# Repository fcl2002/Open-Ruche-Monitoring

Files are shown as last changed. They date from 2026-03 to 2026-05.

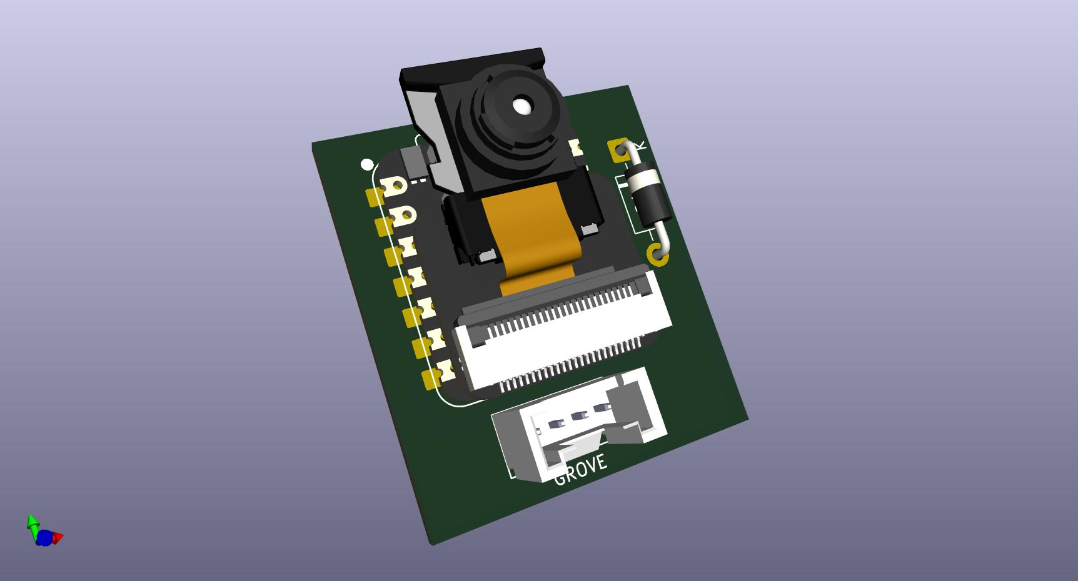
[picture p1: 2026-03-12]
hardware/3D_XIAO_view.jpg

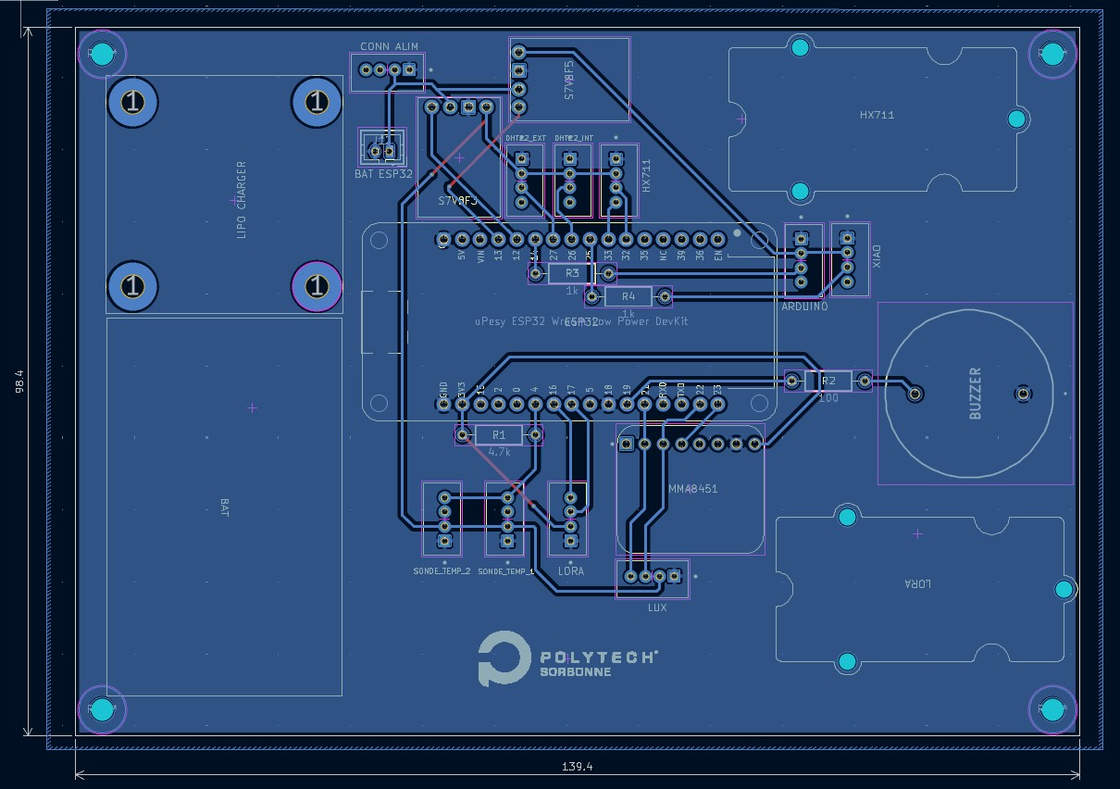
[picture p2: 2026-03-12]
hardware/pcb.jpg

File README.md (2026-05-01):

# Open Ruche 🐝 — BEE SMART

**Système de Monitorage Autonome de Ruches en Temps-réel**  
_Protéger les abeilles, préserver demain._

An intelligent beehive monitoring solution combining embedded AI, LoRaWAN communication, and solar power to help beekeepers protect their colonies and optimize hive management.

---

## Context & Motivation

Bee colonies face an accelerating global decline driven by the *Varroa destructor* mite, the Asian hornet (*Vespa velutina*), pesticides, and climate change. Continuous 24/7 manual monitoring is impossible for beekeepers — Open Ruche fills that gap with autonomous, real-time surveillance and automatic threat detection.

---

## Team

| Role | Name |
|---|---|
| **Project Manager, System Integration & Firmware Lead** | [Fernando COSTA LASMAR](https://www.linkedin.com/in/fernando-costa-lasmar/) |
| **AI/ML Engineer & Model Development** | [Flávio ROSIM DE SOUSA](https://www.linkedin.com/in/flávio-rosim-de-sousa/) |
| **Hardware Design & PCB Engineer** | [Matheus SISTON GALDINO](https://www.linkedin.com/in/matheussistongaldino/) |
| **Power Management & Solar Systems** | [Karim SAWAYA](https://www.linkedin.com/in/karim-sawaya-67ab87292/) |
| **HMI & Documentation** | [Yan DING](mailto:dingyan02040608@gmail.com) |

**Academic context:** Polytech Sorbonne — EI4 FISE | Projet Systèmes Embarqués IoT 2025-2026 | Groupe 4 – Ruche 9

---

## Solution Overview

Open Ruche is built around four integrated layers:

**Power Layer**
- Solar panel + battery with charge management module
- Switchable voltage regulator for load optimization
- Deep Sleep mode bringing average draw down to ~0.822 mA

**Sensor Layer (custom PCB)**
- Temperature: 2× DS18B20 probes (internal) + 1× DHT22 (external T°/humidity)
- Weight: HX711 load cell amplifier
- Light: LUX sensor
- Motion/safety: MMA8452 accelerometer, GPS module, buzzer alarm
- Air quality: gas/particle sensor (SEN0190)

**AI Processing Layer**
- Dual-core setup: Arduino Nano 3.3 (audio) + XIAO ESP32S3 (vision)
- TensorFlow Lite models running fully on-device
- **Audio classification model** — 86.45% accuracy on test data
  - Class 1: Normal activity
  - Class 2: Swarming
  - Class 3: Queenless colony
- **Hornet detection model (computer vision)** — 79.7% accuracy, F1-score 90%
  - Code 0: No hornet detected
  - Code 1: Hornet detected

**Communication & Cloud Layer**
- LoRaWAN module → The Things Network (TTN)
- Configurable uplink frequency via TTN downlink
- Cloud dashboards: BEEP Monitor + Datacake
- Real-time alerts and remote parameter configuration

---

## Software Architecture

The firmware implements a 4-state machine to minimise power consumption:

```
BOOT → INIT → LECTURE (sensors + AI) → DEEP SLEEP
              ↑___________________________________|
              Wake after configurable interval
```

- **INIT → LECTURE** triggered when LUX > 100 AND internal temp > 20 °C  
- **LECTURE → DEEP SLEEP** when LUX < 100 OR internal temp < 15 °C  
- LoRa downlink allows remote configuration of the sleep interval  
- Logging system for debugging and field maintenance

---

## Power Consumption

| Phase | Average Current |
|---|---|
| Active period (AI + sensors + LoRa) | ~85.8 mA |
| Deep Sleep | ~0.822 mA |

Charge breakdown per cycle (54 s total):
- AI (10 s): 0.414 mAh — 38%
- Sensors (15 s): 0.283 mAh — 26%
- LoRa (9 s): 0.117 mAh — 11%
- Deep Sleep (20 min): 0.274 mAh — 25%

**Estimated autonomy (1000 mAh battery):** ~13 days without solar charging.

---

## Project Status

| Objective | Status |
|---|---|
| Sensor accuracy & LoRa transmission | ✅ Done |
| Real-time image & audio AI detection | ✅ Done |
| Alarm creation & notifications | ✅ Done |
| Remote parameter & alarm configuration | ✅ Done |
| System energy autonomy | ✅ Done |
| PCB schematic & assembly | ✅ Done |
| Enclosure fabrication & prototype wiring | ✅ Done |
| Data display on cloud platforms | ✅ Done |
| Accelerometer for fall/theft detection | ❌ Not implemented |

---

## Getting Started

### Prerequisites

- Arduino IDE or PlatformIO
- KiCad (for hardware design)
- The Things Network account + LoRaWAN gateway access

### Quick Start

```bash
# Clone the repository
git clone https://github.com/[your-username]/OpenRuche.git
cd OpenRuche

# Project structure
# hardware/   — KiCad schematics & PCB files
# software/   — Firmware (Arduino / PlatformIO)
# ai/         — TensorFlow Lite model training scripts
# docs/       — Documentation & guides
```

For detailed development guidelines, see [CONTRIBUTING.md](CONTRIBUTING.md).

---

## License

This project is open-source. See [LICENSE](LICENSE) for details.

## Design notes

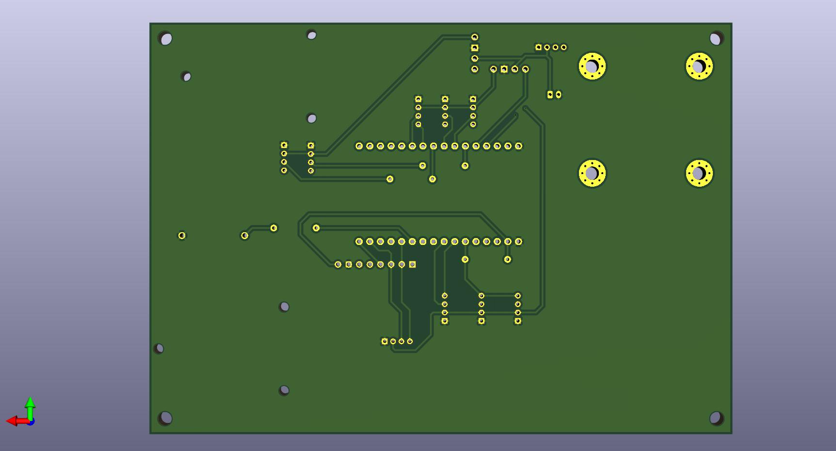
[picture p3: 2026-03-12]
hardware/PCB_bottom.jpg

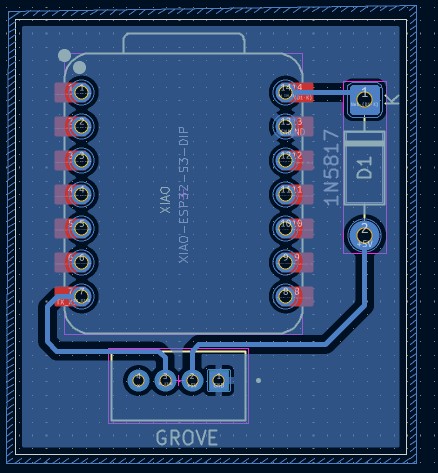
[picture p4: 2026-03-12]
hardware/pcb_xiao.jpg

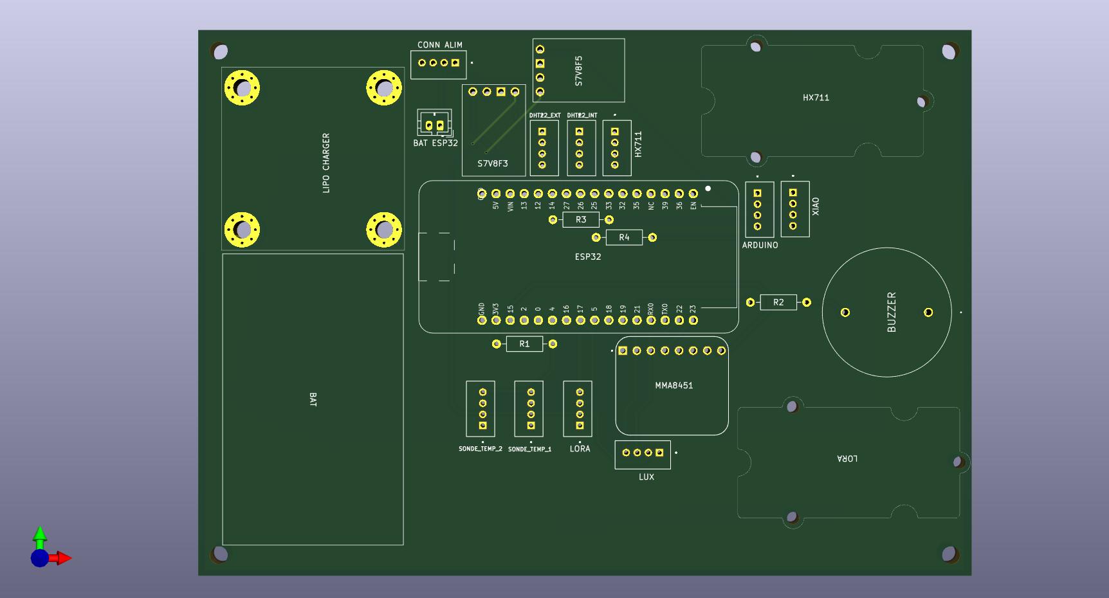
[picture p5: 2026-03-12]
hardware/PCB_top.jpg

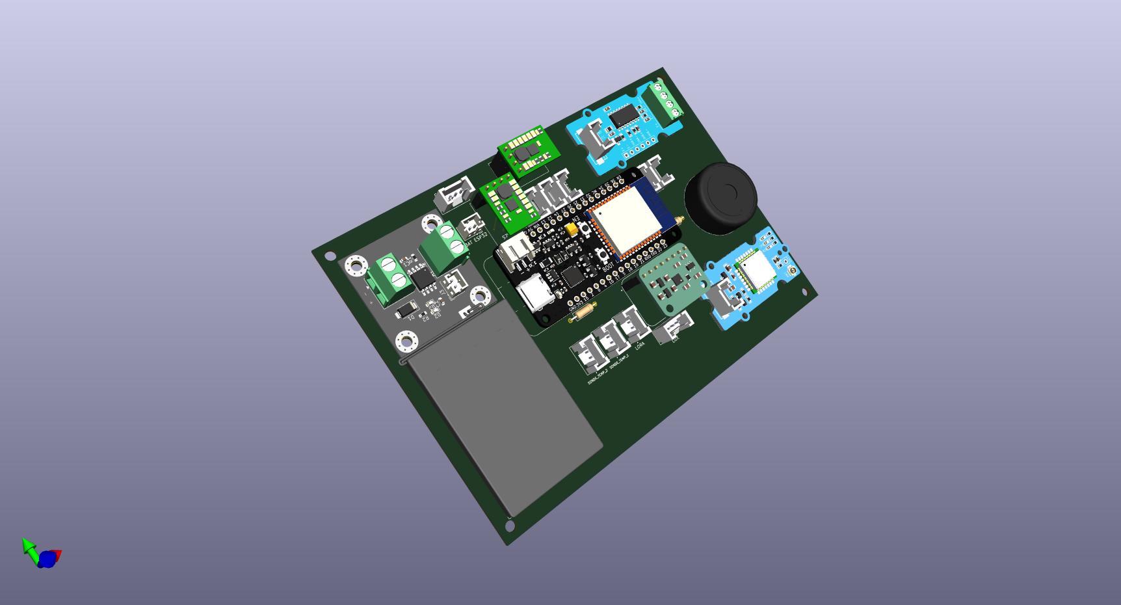
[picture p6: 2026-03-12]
hardware/3D_view.jpg

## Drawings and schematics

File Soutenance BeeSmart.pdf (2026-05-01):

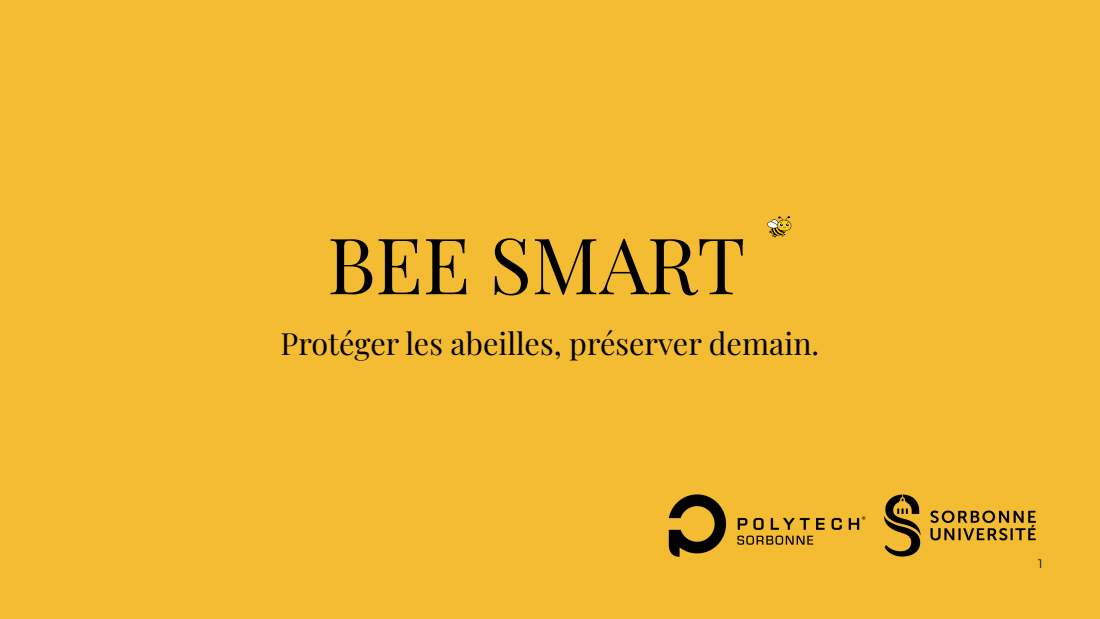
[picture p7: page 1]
BEE SMART

Protéger les abeilles, préserver demain.

E

QU

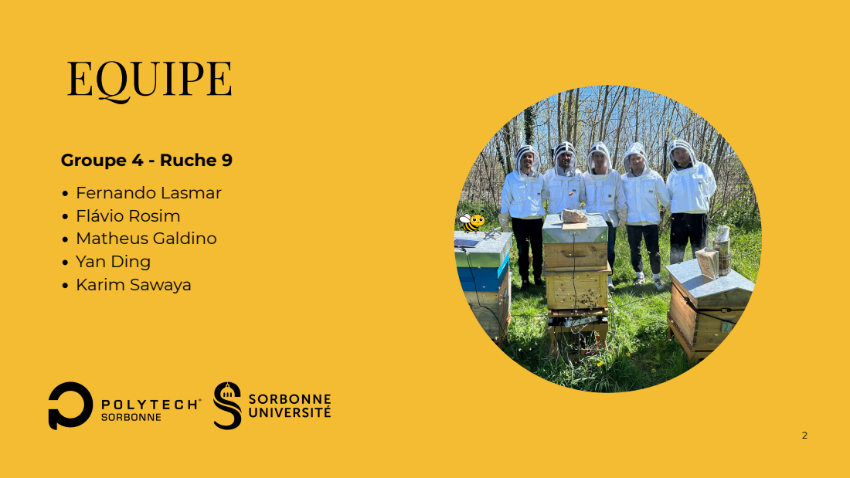
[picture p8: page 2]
Flá; vio; sim; aldin; Din; rim

# CONTEXTE

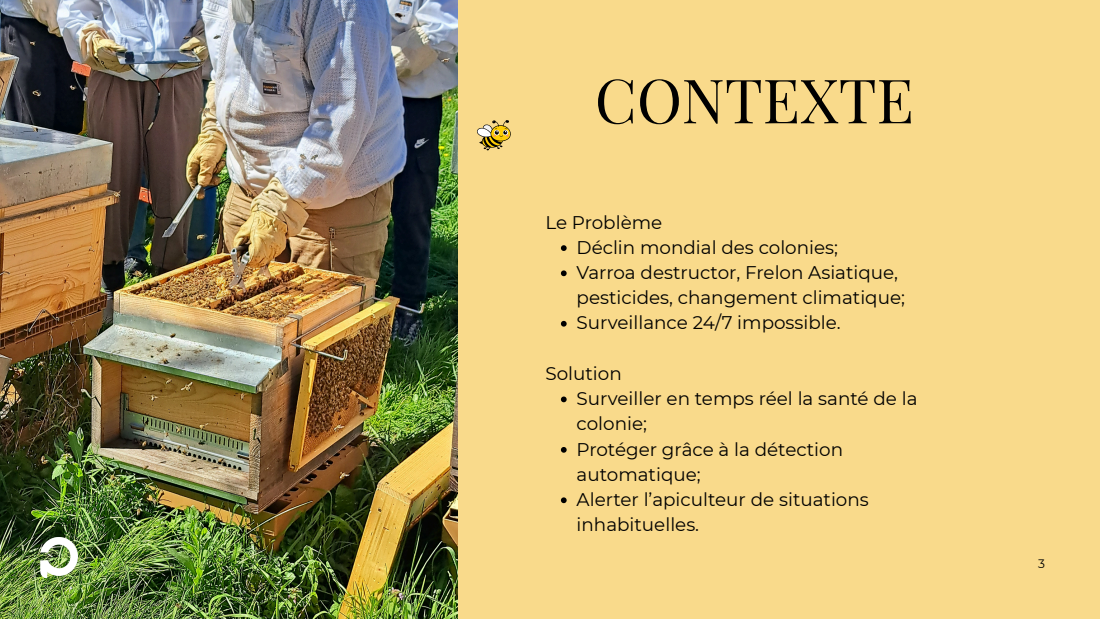
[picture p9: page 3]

Le Problème
Déclin mondial des colonies;
Varroa destructor, Frelon Asiatique,
pesticides, changement climatique;
Surveillance 24/7 impossible.

Solution
Surveiller en temps réel la santé de la
colonie;
Protéger grâce à la détection
automatique;
Alerter l’apiculteur de situations
inhabituelles.

# SOLUTION

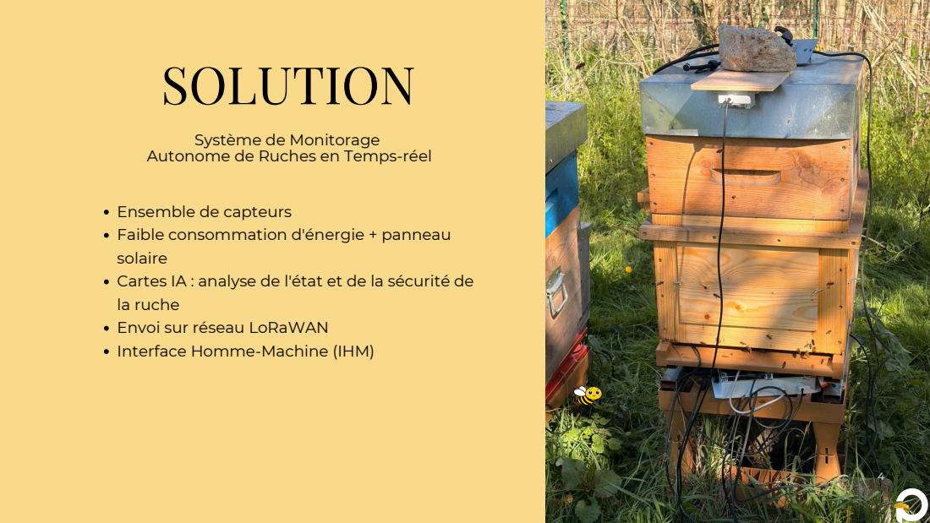
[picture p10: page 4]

Système de Monitorage
Autonome de Ruches en Temps-réel

Ensemble de capteurs
Faible consommation d'énergie + panneau
solaire
Cartes IA : analyse de l'état et de la sécurité de
la ruche
Envoi sur réseau LoRaWAN
Interface Homme-Machine (IHM)

# HARDWARE

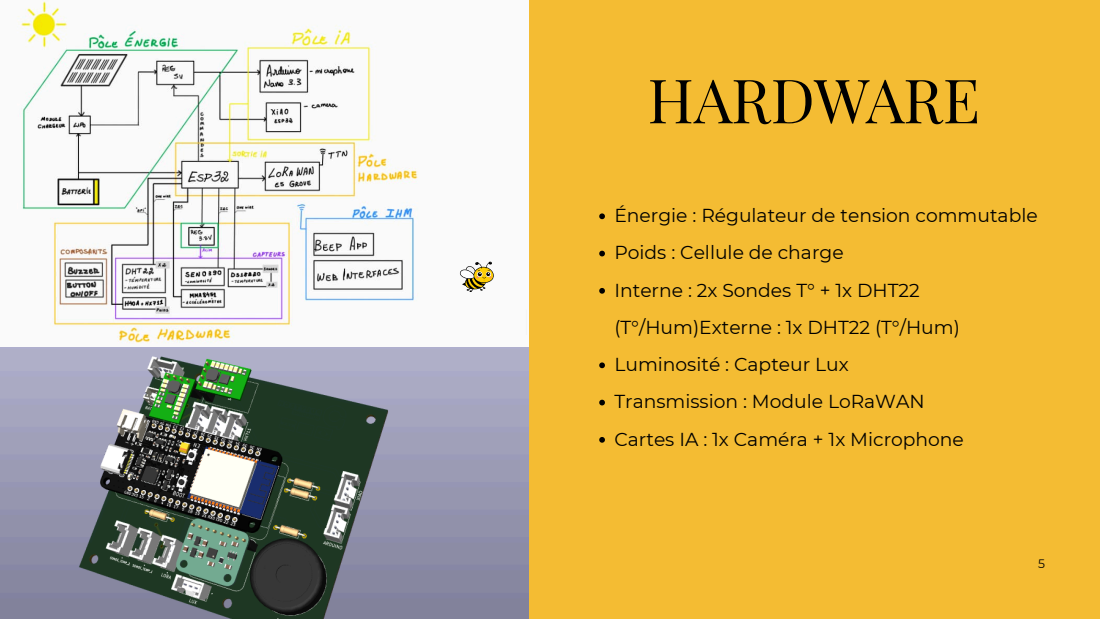
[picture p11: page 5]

Énergie : Régulateur de tension commutable
Poids : Cellule de charge
Interne : 2x Sondes T° + 1x DHT22
(T°/Hum)Externe : 1x DHT22 (T°/Hum)
Luminosité : Capteur Lux
Transmission : Module LoRaWAN
Cartes IA : 1x Caméra + 1x Microphone

S

O

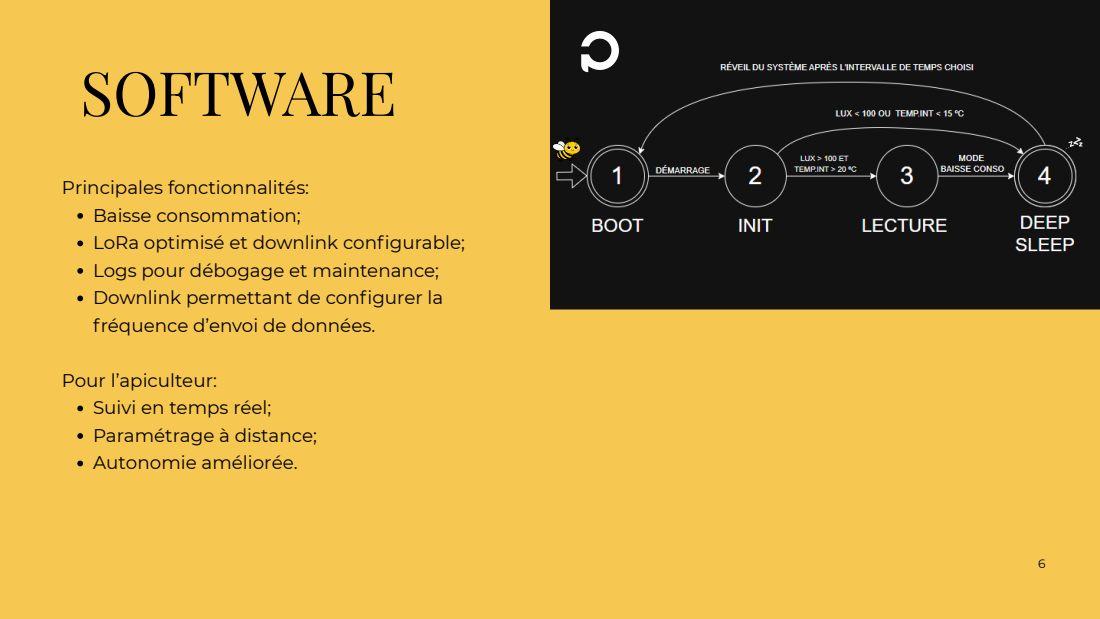
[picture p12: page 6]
rin; cip; ale; tio; alit; fig; ble; Logs pour débogage et maintenance; Downlink permettant de configurer la fréquence d’envoi de données. Pour l’apiculteur: Suivi en temps réel; Paramétrage à distance; Autonomie améliorée.

s: Baisse consommation; LoRa optimisé et downlin

# RÉSULTATS

IA

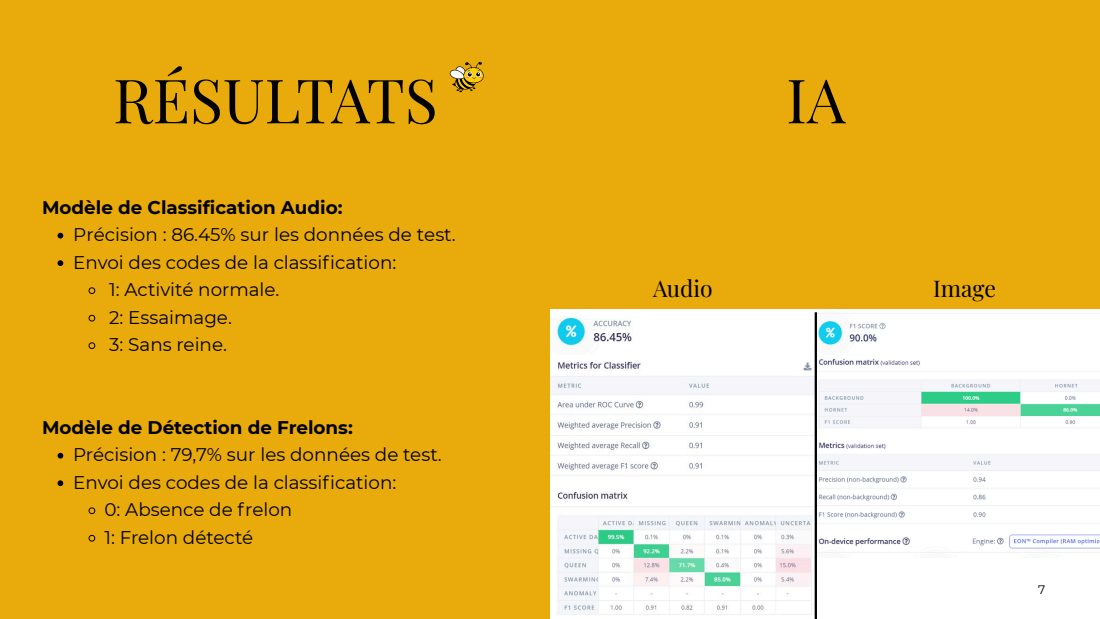
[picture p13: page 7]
Audio; Image

Modèle de Classification Audio:
Précision : 86.45% sur les données de test.
Envoi des codes de la classification:
1: Activité normale.
2: Essaimage.
3: Sans reine.

Modèle de Détection de Frelons:
Précision : 79,7% sur les données de test.
0: Absence de frelon
1: Frelon détecté

# CONSOMMATION

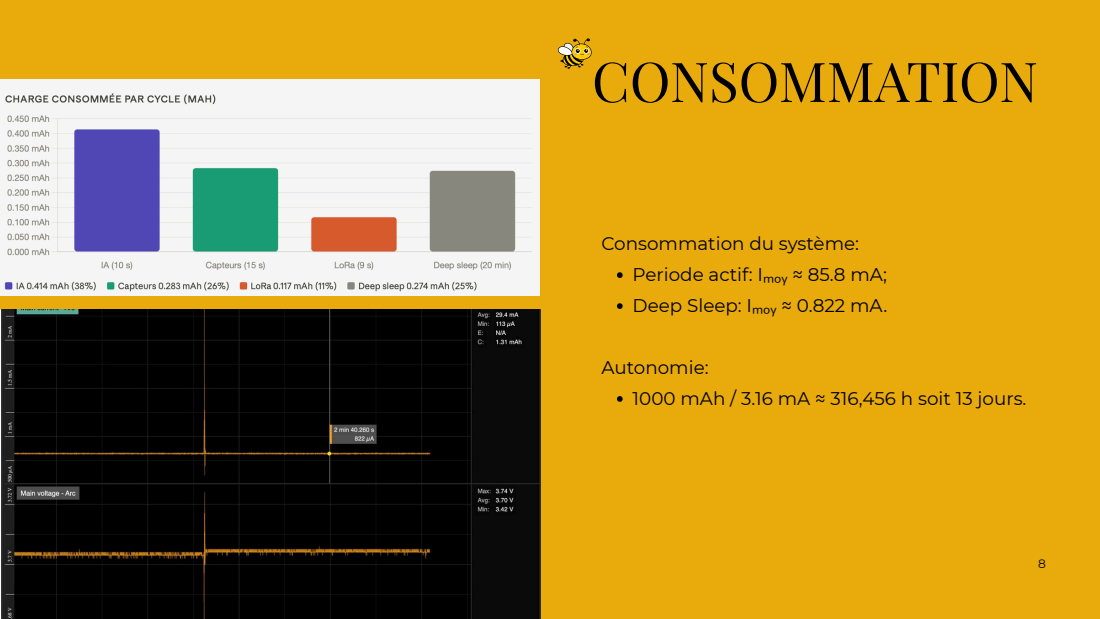
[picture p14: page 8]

Consommation du système:
Periode actif: Iₘₒᵧ ≈ 85.8 mA;
Deep Sleep: Iₘₒᵧ ≈ 0.822 mA.

Autonomie:
1000 mAh / 3.16 mA ≈ 316,456 h soit 13 jours.

# Suivi

# Objectifs

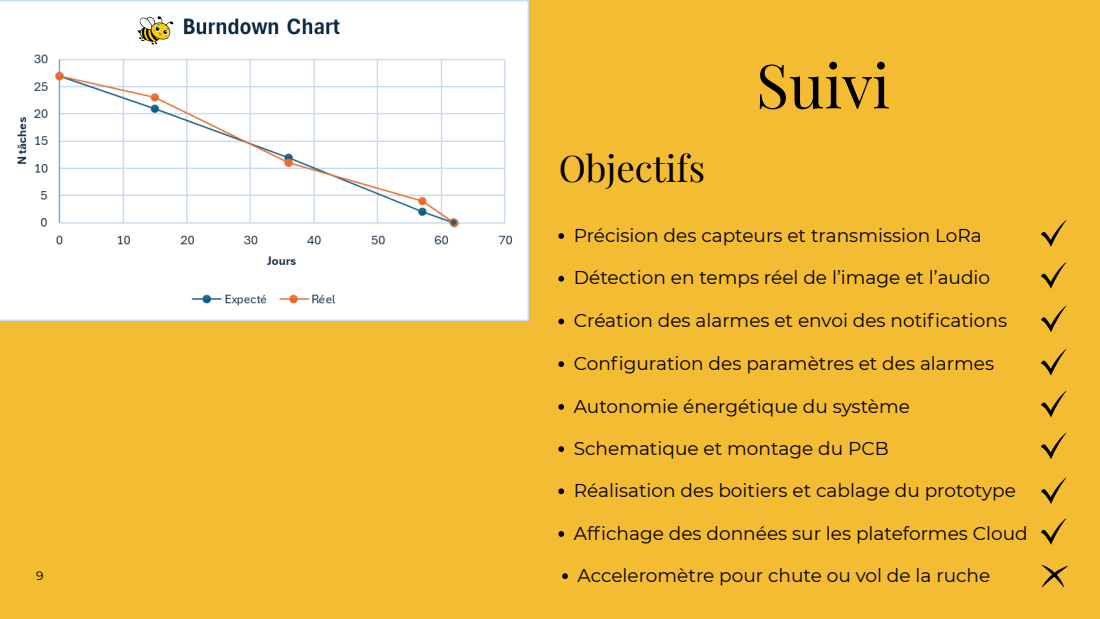
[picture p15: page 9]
Acceleromètre pour chute ou vol de la ruche

Précision des capteurs et transmission LoRa
Détection en temps réel de l’image et l’audio
Création des alarmes et envoi des notifications
Configuration des paramètres et des alarmes
Autonomie énergétique du système
Schematique et montage du PCB
Réalisation des boitiers et cablage du prototype
Affichage des données sur les plateformes Cloud

D

É

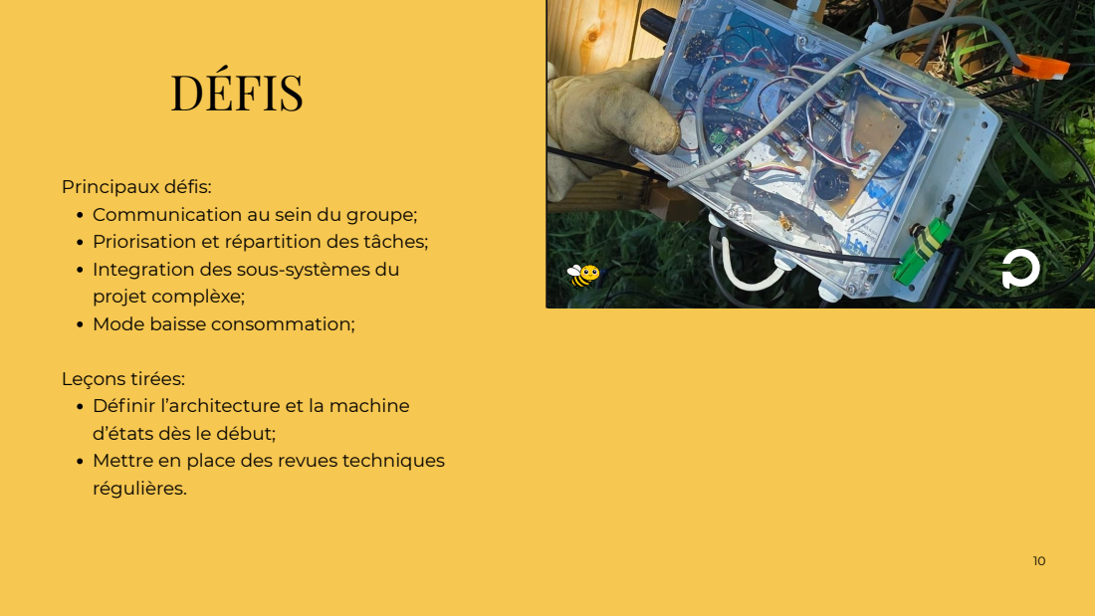
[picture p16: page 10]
rin; cip; fis: Communicatio; ein; uliè

e; Priorisation et répartition des tâches; Integration des sous-systèmes du projet complèxe; Mode baisse consommation; Leçons tirées: Définir l’architecture et la machine d’états dès le début; Mettre en place des revues technique

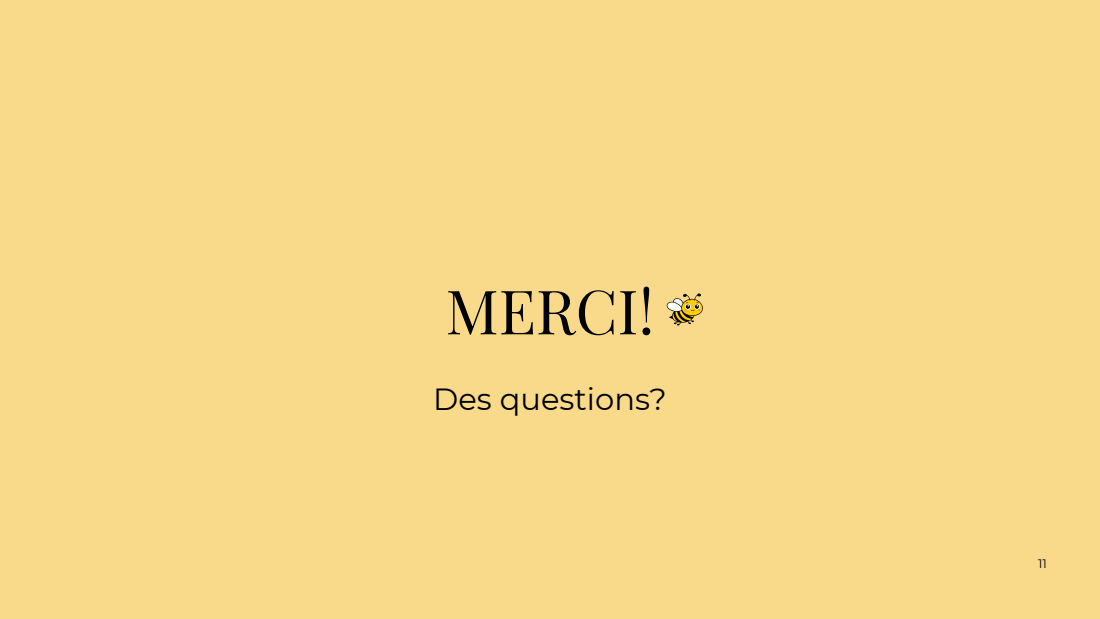
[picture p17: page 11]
MERCI!; Des questions?

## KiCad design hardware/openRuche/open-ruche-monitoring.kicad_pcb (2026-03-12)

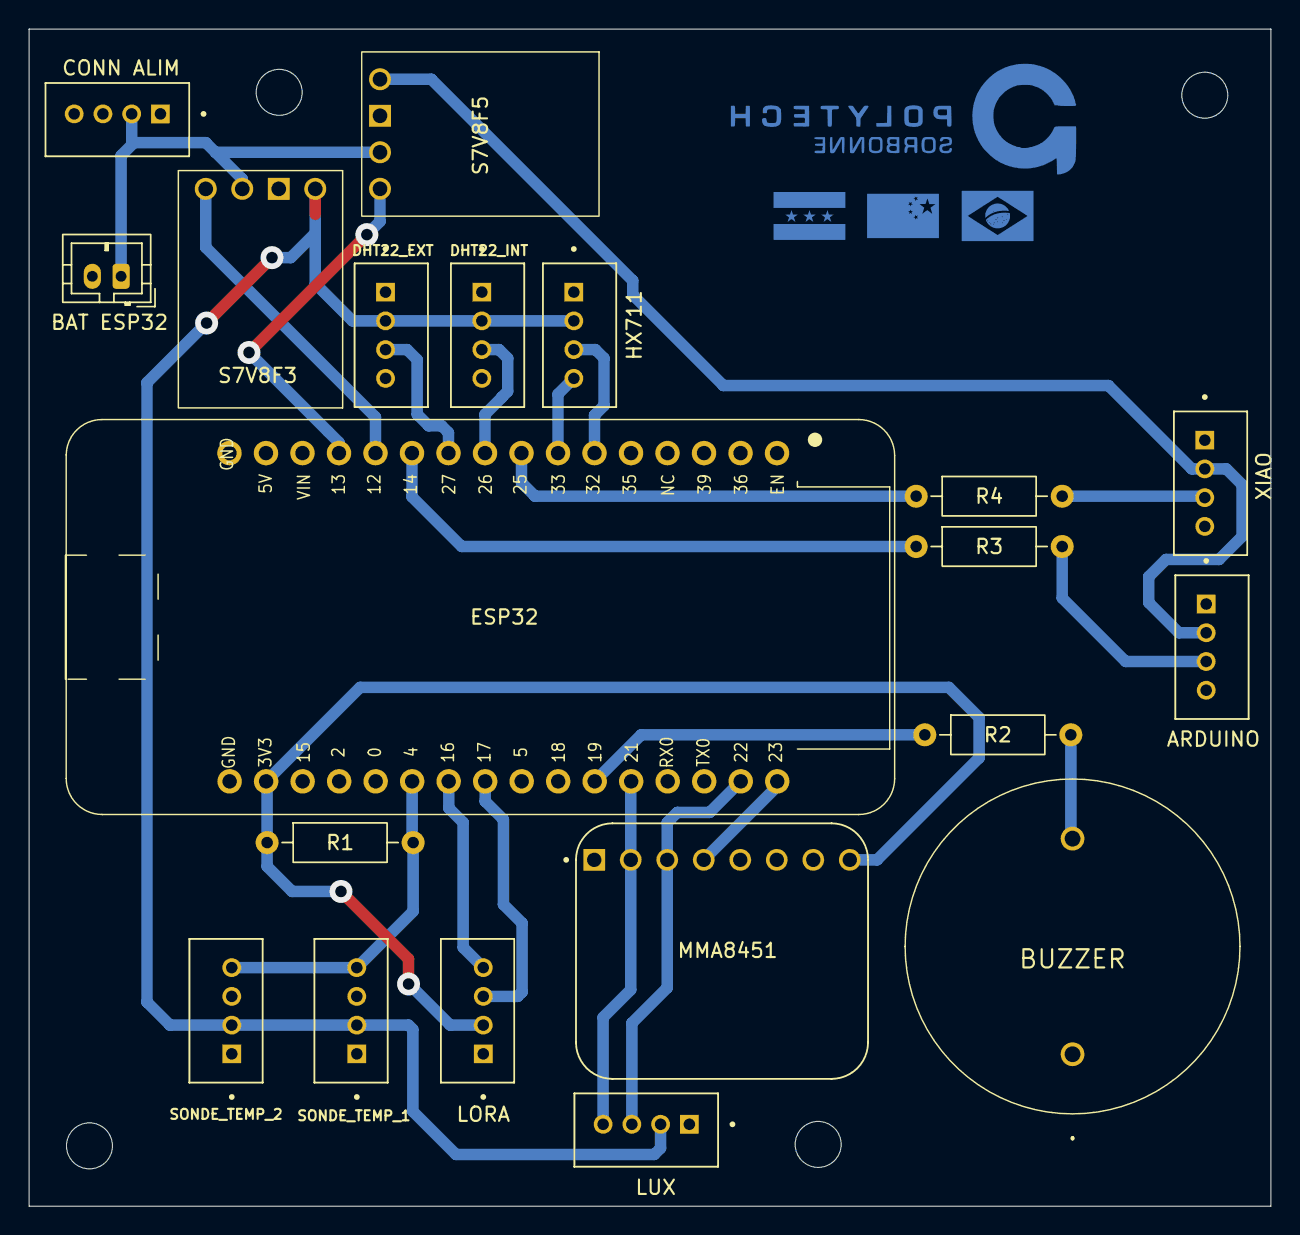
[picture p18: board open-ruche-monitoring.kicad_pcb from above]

Board: 2 copper layers, 86.4 x 81.9 mm, 20 parts (0 on the bottom side), 23 nets.

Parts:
BUZZER: KPEG222
J1: HX711; SEEED_110990030
J2: DHT22_EXT; SEEED_110990030
J3: DHT22_INT; SEEED_110990030
J4: SONDE_TEMP_1; SEEED_110990030
J5: SONDE_TEMP_2; SEEED_110990030
J6: LUX; SEEED_110990030
J7: LORA; SEEED_110990030
J8: ARDUINO; SEEED_110990030
J9: XIAO; SEEED_110990030
J10: MMA8451; MODULE_2019
J11: CONN ALIM; SEEED_110990030
J12: BAT ESP32; JST_PH_B2B-PH-K_1x02_P2.00mm_Vertical
R1: 4.7k; R_Axial_DIN0207_L6.3mm_D2.5mm_P10.16mm_Horizontal
R2: 100; R_Axial_DIN0207_L6.3mm_D2.5mm_P10.16mm_Horizontal
R3, R4: 1k; R_Axial_DIN0207_L6.3mm_D2.5mm_P10.16mm_Horizontal
U1: uPesy ESP32 Wroom Low Power DevKit; uPesy_ESP32_Wroom_Low_Power_DevKit
U2: S7V8F3; MODULE_STEP-DOWN_VOLTAGE_REGULATOR_D24V6F3
U3: S7V8F5; MODULE_STEP-DOWN_VOLTAGE_REGULATOR_D24V6F3

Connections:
/+3.3V: J7.2 (VCC), J10.8, R1.1, U1.31 (3V3)
/+3.3V_REG: J1.2 (VCC), J2.2 (VCC), J3.2 (VCC), J4.2 (VCC), J5.2 (VCC), J6.2 (VCC), U2.VOUT
/+3.7V: J11.2 (VCC), J12.1, U2.VIN, U3.VIN
/+5V_REG: J8.2 (VCC), J9.2 (VCC), U3.VOUT
/BUZZER: R2.1, U1.22 (GPIO19)
/DATA_DHT22_EXT: J2.3 (SIG1), U1.10 (GPIO27)
/DATA_DHT22_INT: J3.3 (SIG1), U1.9 (GPIO26)
/DOUT: J1.3 (SIG1), U1.6 (GPIO32)
/EN_3.3V_REG: U1.12 (GPIO12), U2.!SHDN (~SHDN)
/EN_5V_REG: U1.13 (GPIO13), U3.!SHDN (~SHDN)
/I1: J10.4, U1.17 (GPIO23)
/ONE_WIRE_TEMP: J4.4 (SIG2), J5.4 (SIG2), R1.2, U1.27 (GPIO4)
/PSCK: J1.4 (SIG2), U1.7 (GPIO33)
/RX_LORA: J7.3 (SIG1), U1.25 (GPIO17)
/SCL: J6.3 (SIG1), J10.3, U1.18 (GPIO22)
/SDA: J6.4 (SIG2), J10.2, U1.21 (GPIO21)
/TX_ARDUINO: R3.1, U1.11 (GPIO14)
/TX_LORA: J7.4 (SIG2), U1.26 (GPIO16)
/TX_XIAO: R4.1, U1.8 (GPIO25)
GND: BUZZER.1 (-), J1.1 (GND), J2.1 (GND), J3.1 (GND), J4.1 (GND), J5.1 (GND), J6.1 (GND), J7.1 (GND), J8.1 (GND), J9.1 (GND), J10.7, J11.1 (GND), J12.2, U1.16 (GND), U1.23 (GPIO18), U1.32 (GND), U2.GND, U3.GND
unnamed: J8.3 (SIG1), R3.2
unnamed: J9.3 (SIG1), R4.2
unnamed: BUZZER.2 (+), R2.2

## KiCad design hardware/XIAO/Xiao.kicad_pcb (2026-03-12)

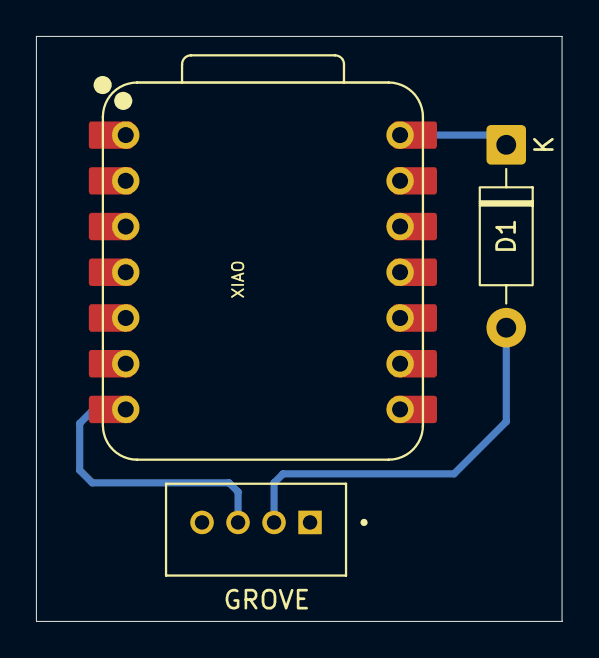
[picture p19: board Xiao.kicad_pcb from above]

Board: 2 copper layers, 29.2 x 32.5 mm, 3 parts (0 on the bottom side), 4 nets.

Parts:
D1: 1N5817; D_DO-41_SOD81_P10.16mm_Horizontal
J1: GROVE; SEEED_110990030
XIAO: XIAO-ESP32-S3-DIP

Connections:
/+5V: D1.2 (A), J1.2 (VCC)
/TX_XIAO: J1.3 (SIG1), XIAO.7 (GPIO43_D6_TX)
GND: J1.1 (GND), XIAO.13 (GND)
unnamed: D1.1 (K), XIAO.14 (VBUS)

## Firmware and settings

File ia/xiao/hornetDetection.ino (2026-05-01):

/* Edge Impulse Arduino examples - Modified for BeeGuard Production (Deep Sleep / Latch) */
#include <BeeGuardAI_Hornet_inferencing.h>
#include "edge-impulse-sdk/dsp/image/image.hpp"
#include "esp_camera.h"

#define UART_TX_PIN 43 // D6 on XIAO ESP32S3
#define UART_RX_PIN 44 // D7 on XIAO ESP32S3
HardwareSerial SerialVespa(1); // Uses ESP32 UART channel 1

// Select camera model for XIAO ESP32S3 Sense
#define CAMERA_MODEL_XIAO_ESP32S3 // Has PSRAM

#if defined(CAMERA_MODEL_XIAO_ESP32S3)
#define PWDN_GPIO_NUM     -1
#define RESET_GPIO_NUM    -1
#define XCLK_GPIO_NUM     10
#define SIOD_GPIO_NUM     40
#define SIOC_GPIO_NUM     39
#define Y9_GPIO_NUM       48
#define Y8_GPIO_NUM       11
#define Y7_GPIO_NUM       12
#define Y6_GPIO_NUM       14
#define Y5_GPIO_NUM       16
#define Y4_GPIO_NUM       18
#define Y3_GPIO_NUM       17
#define Y2_GPIO_NUM       15
#define VSYNC_GPIO_NUM    38
#define HREF_GPIO_NUM     47
#define PCLK_GPIO_NUM     13
#else
#error "Camera model not selected or not supported"
#endif

/* ------------------------------------------------------------------------- */
/* PRODUCTION SETTINGS AND ANTI-FALSE POSITIVE FILTER                        */
/* ------------------------------------------------------------------------- */
#define DEBUG_SERIAL           1     // Set to 1 only if you want to read human-readable error/timing prints
#define CONFIDENCE_THRESHOLD   0.70f 
#define REQUIRED_DETECTIONS    4     
#define TIME_WINDOW_MS         5000  // Time window: must detect 4 times within 5 seconds

const char* TARGET_LABEL = "Hornet"; 

// Native capture resolution
#define EI_CAMERA_RAW_FRAME_BUFFER_COLS           320
#define EI_CAMERA_RAW_FRAME_BUFFER_ROWS           240
#define EI_CAMERA_FRAME_BYTE_SIZE                 3

/* Private Variables ------------------------------------------------------- */
static bool debug_nn = false;
static bool is_initialised = false;
uint8_t *snapshot_buf; 

static unsigned long detection_times[REQUIRED_DETECTIONS] = {0};
static int detections_in_buffer = 0;

// ADDED: Alarm latch variable
static bool alarm_triggered = false; 

static camera_config_t camera_config = {
    .pin_pwdn = PWDN_GPIO_NUM,  .pin_reset = RESET_GPIO_NUM, .pin_xclk = XCLK_GPIO_NUM,
    .pin_sccb_sda = SIOD_GPIO_NUM, .pin_sccb_scl = SIOC_GPIO_NUM,
    .pin_d7 = Y9_GPIO_NUM, .pin_d6 = Y8_GPIO_NUM, .pin_d5 = Y7_GPIO_NUM, .pin_d4 = Y6_GPIO_NUM,
    .pin_d3 = Y5_GPIO_NUM, .pin_d2 = Y4_GPIO_NUM, .pin_d1 = Y3_GPIO_NUM, .pin_d0 = Y2_GPIO_NUM,
    .pin_vsync = VSYNC_GPIO_NUM, .pin_href = HREF_GPIO_NUM, .pin_pclk = PCLK_GPIO_NUM,
    .xclk_freq_hz = 20000000, .ledc_timer = LEDC_TIMER_0, .ledc_channel = LEDC_CHANNEL_0,
    .pixel_format = PIXFORMAT_JPEG, .frame_size = FRAMESIZE_QVGA,
    .jpeg_quality = 12, .fb_count = 1, .fb_location = CAMERA_FB_IN_PSRAM, .grab_mode = CAMERA_GRAB_WHEN_EMPTY,
};

bool ei_camera_init(void);
void ei_camera_deinit(void);
bool ei_camera_capture(uint32_t img_width, uint32_t img_height, uint8_t *out_buf);
static int ei_camera_get_data(size_t offset, size_t length, float *out_ptr);

void setup() {
    Serial.begin(115200);
    while (!Serial);
    
    SerialVespa.begin(115200, SERIAL_8N1, UART_RX_PIN, UART_TX_PIN);

    if (DEBUG_SERIAL) Serial.println("Starting BeeGuard - Production Mode (With Latch)");
    
    if (ei_camera_init() == false) {
        if (DEBUG_SERIAL) Serial.println("Camera initialization failed!");
        while(1); // Halt if camera fails to start
    }
}

void loop() {
    // ADDED: If hornet already detected, latch here! 
    // Keeps sending '1' and saves battery by not taking new photos, waiting for power cut.
    if (alarm_triggered) {
        SerialVespa.write(1);
        if (DEBUG_SERIAL) Serial.println("LATCHED STATE: Sending 1... Waiting for power cut.");
        ei_sleep(250); // Sends approximately 4 times per second
        return; 
    }

    ei_sleep(10); 
    unsigned long current_time = ei_read_timer_ms();

    snapshot_buf = (uint8_t*)malloc(EI_CAMERA_RAW_FRAME_BUFFER_COLS * EI_CAMERA_RAW_FRAME_BUFFER_ROWS * EI_CAMERA_FRAME_BYTE_SIZE);
    if(snapshot_buf == nullptr) return;

    ei::signal_t signal;
    signal.total_length = EI_CLASSIFIER_INPUT_WIDTH * EI_CLASSIFIER_INPUT_HEIGHT;
    signal.get_data = &ei_camera_get_data;

    if (ei_camera_capture((size_t)EI_CAMERA_RAW_FRAME_BUFFER_COLS, (size_t)EI_CAMERA_RAW_FRAME_BUFFER_ROWS, snapshot_buf) == false) {
        free(snapshot_buf);
        return;
    }

    uint8_t *inference_buf = (uint8_t*)malloc(EI_CLASSIFIER_INPUT_WIDTH * EI_CLASSIFIER_INPUT_HEIGHT * EI_CAMERA_FRAME_BYTE_SIZE);
    if(inference_buf == nullptr) {
        free(snapshot_buf); return;
    }

    ei::image::processing::crop_and_interpolate_rgb888(
        snapshot_buf, EI_CAMERA_RAW_FRAME_BUFFER_COLS, EI_CAMERA_RAW_FRAME_BUFFER_ROWS,
        inference_buf, EI_CLASSIFIER_INPUT_WIDTH, EI_CLASSIFIER_INPUT_HEIGHT);

    memcpy(snapshot_buf, inference_buf, EI_CLASSIFIER_INPUT_WIDTH * EI_CLASSIFIER_INPUT_HEIGHT * EI_CAMERA_FRAME_BYTE_SIZE);
    free(inference_buf);

    ei_impulse_result_t result = { 0 };
    EI_IMPULSE_ERROR err = run_classifier(&signal, &result, debug_nn);
    if (err != EI_IMPULSE_OK) {
        free(snapshot_buf); return;
    }

    if (DEBUG_SERIAL) {
        Serial.print("Inference OK | Timing: ");
        Serial.print(result.timing.classification);
        Serial.print("ms | ");
        
        bool saw_something = false;
        for (uint32_t i = 0; i < result.bounding_boxes_count; i++) {
            if (result.bounding_boxes[i].value > 0.40) { // Show if at least 40% confidence
                Serial.print("Detected: ");
                Serial.print(result.bounding_boxes[i].label);
                Serial.print(" (");
                Serial.print(result.bounding_boxes[i].value);
                Serial.print(")  ");
                saw_something = true;
            }
        }
        if (!saw_something) {
            Serial.print("Nothing on radar.");
        }
        Serial.println();
    }

    /* --------------------------------------------------------------------- */
    /* NEW LOGIC: SLIDING WINDOW WITH LATCHING                               */
    /* --------------------------------------------------------------------- */
    bool hornet_in_this_frame = false;

    for (uint32_t i = 0; i < result.bounding_boxes_count; i++) {
        ei_impulse_result_bounding_box_t bb = result.bounding_boxes[i];
        if (bb.value >= CONFIDENCE_THRESHOLD && strcmp(bb.label, TARGET_LABEL) == 0) {
            hornet_in_this_frame = true;
            break; 
        }
    }

    if (hornet_in_this_frame) {
        // Shift old history to the left
        for (int i = 0; i < REQUIRED_DETECTIONS - 1; i++) {
            detection_times[i] = detection_times[i+1];
        }
        // Store new detection in the most recent position (right)
        detection_times[REQUIRED_DETECTIONS - 1] = current_time;

        if (detections_in_buffer < REQUIRED_DETECTIONS) {
            detections_in_buffer++;
        }

        // If memory is full (we have 4 recorded detections)
        if (detections_in_buffer == REQUIRED_DETECTIONS) {
            // Compare the most recent detection with the oldest recorded one
            unsigned long oldest_detection = detection_times[0];
            
            if (current_time - oldest_detection <= TIME_WINDOW_MS) {
                // ALARM CONFIRMED! 4 hornets detected within the time window!
                alarm_triggered = true; // ACTIVATE LATCH HERE
                SerialVespa.write(1); 
                
                if(DEBUG_SERIAL) Serial.println("=========================================");
                if(DEBUG_SERIAL) Serial.println("MAXIMUM ALERT: HORNET CONFIRMED ON PIN D6!");
                if(DEBUG_SERIAL) Serial.println("=========================================");
                
            } else {
                // Hornet seen, but old ones have already expired
                SerialVespa.write(0);
            }
        } else {
            SerialVespa.write(0); // Accumulating, haven't reached 4 yet
        }
    } else {
        SerialVespa.write(0); // Nothing in this frame
    }

    free(snapshot_buf);
}


bool ei_camera_init(void) {
    if (is_initialised) return true;
    esp_err_t err = esp_camera_init(&camera_config);
    if (err != ESP_OK) return false;
    sensor_t * s = esp_camera_sensor_get();
    if (s->id.PID == OV3660_PID) {
      s->set_vflip(s, 1); s->set_brightness(s, 1); s->set_saturation(s, 0);
    }
#if defined(CAMERA_MODEL_XIAO_ESP32S3)
    s->set_vflip(s, 1); s->set_hmirror(s, 1);
#endif
    is_initialised = true; return true;
}

void ei_camera_deinit(void) {
    esp_err_t err = esp_camera_deinit();
    if (err == ESP_OK) is_initialised = false;
}

bool ei_camera_capture(uint32_t img_width, uint32_t img_height, uint8_t *out_buf) {
    if (!is_initialised) return false;
    camera_fb_t *fb = esp_camera_fb_get();
    if (!fb) return false;
    bool converted = fmt2rgb888(fb->buf, fb->len, PIXFORMAT_JPEG, snapshot_buf);
    esp_camera_fb_return(fb);
    return converted;
}

static int ei_camera_get_data(size_t offset, size_t length, float *out_ptr) {
    size_t pixel_ix = offset * 3;
    size_t pixels_left = length;
    size_t out_ptr_ix = 0;
    while (pixels_left != 0) {
        out_ptr[out_ptr_ix] = (snapshot_buf[pixel_ix + 2] << 16) + (snapshot_buf[pixel_ix + 1] << 8) + snapshot_buf[pixel_ix];
        out_ptr_ix++; pixel_ix+=3; pixels_left--;
    }
    return 0;
}

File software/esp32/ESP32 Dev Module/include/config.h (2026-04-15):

/**
 *
 * Central configuration for Open Ruche Project
 * https://github.com/fcl2002/Open-Ruche-Monitoring
 *
 * MIT License
 * (c) 2026 Fernando Lasmar
 *
**/
#ifndef CONFIG_H
#define CONFIG_H

// ── Debug mode ───────────────────────────────────────────────
// 1 = enable Serial initialization and debug logs
// 0 = keep Serial disabled for production/low-power operation
#define DEBUG_MODE              0

// ── Deep sleep ────────────────────────────────────────────────
#define DEEP_SLEEP_DURATION_S   15       // Normal cycle: sleep and wake interval (seconds)
#define DEEP_SLEEP_LORA_S       120      // Normal cycle: sleep and wake interval (seconds)
#define DEEP_SLEEP_DORMANT_S    3600     // Dormant mode: 60 min between checks
#define uS_TO_S_FACTOR          1000000
#define AI_READ_TIME            10000    // AI Boards read time

// ── Activity thresholds ───────────────────────────────────────
// Both conditions must be true to enter the active (uplink) cycle.
// Below either threshold the system stays in dormant deep sleep.
#define LUX_ACTIVITY_THRESHOLD   100   // lux  — minimum daylight level
#define TEMP_ACTIVITY_THRESHOLD  150   // °C×10 — 15.0 °C minimum

// ── Battery ADC ───────────────────────────────────────────────
#define BATTERY_ADC_PIN         35          // ADC1_CH7 — battery voltage sense (V_BAT = 1.435 * raw/4095 * 3.3)

// ── Buzzer ────────────────────────────────────────────────────
#define BUZZER_PIN              19          // Active buzzer enable (HIGH = on)

// ── Voltage regulators ───────────────────────────────────────
#define VREG_3V3_PIN              12          // Regulator 1 enable (HIGH = on)
#define VREG_5V_PIN               13          // Regulator 2 enable (HIGH = on)

// ── I2C pins ──────────────────────────────────────────────────
#define I2C_SDA_PIN             21
#define I2C_SCL_PIN             22

// ── I2C addresses ─────────────────────────────────────────────
#define SEN0562_ADDR            0x23

// ── HX711 ─────────────────────────────────────────────────────
#define HX711_DOUT_PIN          32
#define HX711_SCK_PIN           33
#define HX711_SCALE             30148
#define HX711_OFFSET            134750

// ── DHT22 ─────────────────────────────────────────────────────
#define EXTERNAL_DTH22_DATA_PIN 27
#define INTERNAL_DTH22_DATA_PIN 26

// ── DS18B20 ───────────────────────────────────────────────────
#define ONE_WIRE_BUS            4

// ── Sensor error sentinels ────────────────────────────────────
#define SENSOR_ERROR_VALUE      -32768
#define SENSOR_LUX_ERROR_VALUE  0

// ── Microphone AI board UART (UART1 hardware) ────────────────
#define AI_RX_PIN           14          // ESP32 GPIO receiving microphone AI TX
#define AI_UART_NUM         1           // HardwareSerial index (UART1)
#define AI_BAUD             9600
#define AI_READ_TIMEOUT_MS  500

// ── Camera AI board UART (SoftwareSerial — HW UARTs exhausted) ─
// UART0=USB, UART1=microphone, UART2=LoRa → no HW UART left.
#define CAM_RX_PIN          25          // ESP32 GPIO receiving camera AI TX
#define CAM_BAUD            115200
#define CAM_READ_TIMEOUT_MS 500

// ── LoRa-E5 UART ─────────────────────────────────────────────
#define LORA_RX_PIN              16          // ESP32 GPIO connected to LoRa-E5 TX
#define LORA_TX_PIN              17          // ESP32 GPIO connected to LoRa-E5 RX
#define LORA_SERIAL_NUM          2           // ESP32 HardwareSerial index
#define LORA_DEFAULT_INTERVAL_MS (DEEP_SLEEP_DURATION_S * 1000UL)  // Synchronized with ESP wake cycle

// ── TTN OTAA credentials ─────────────────────────────────────
#define LORA_DEV_EUI  "70B3D57ED0075CEE"
#define LORA_APP_EUI  "0000000000000000"
#define LORA_APP_KEY  "3EEA512460C979FF5FE036D9FAEB077D"

#endif /* CONFIG_H */

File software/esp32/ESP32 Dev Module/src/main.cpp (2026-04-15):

#include <Arduino.h>
#include "config.h"
#include "sensors.h"
#include "errors.h"
#include "logger.h"
#include "payload.h"
#include "sleep.h"
#include "lora.h"
#include "boards.h"
#if DEBUG_MODE
    RTC_DATA_ATTR int bootCount = 0;
#endif
RTC_DATA_ATTR int dormant_streak = 0;  // consecutive dormant boots; reset on active cycle

static void shutdown_and_sleep(uint32_t duration_s) {
    logInfo("Preparing LoRa module for sleep...", "SYSTEM");
    lora_power_off();
    digitalWrite(VREG_3V3_PIN, LOW);
    logInfo("Voltage regulator 3.3V OFF", "SLEEP");
#if DEBUG_MODE
    Serial.flush();
#endif
    enter_deep_sleep(duration_s);
}

void setup() {
#if DEBUG_MODE
    Serial.begin(115200);
    delay(100);
#endif
#if DEBUG_MODE
    ++bootCount;
#endif
#if DEBUG_MODE
    Serial.println("\n----------------------");
    Serial.println(String(bootCount) + "th Boot");
#endif

    buzzer_boot_beep();
    sleep_gpio_release();

    pinMode(VREG_5V_PIN, OUTPUT);
    digitalWrite(VREG_5V_PIN, LOW);
    logInfo("Voltage regulator 5V OFF", "SLEEP");

    pinMode(VREG_3V3_PIN, OUTPUT);
    digitalWrite(VREG_3V3_PIN, HIGH);
    logInfo("Voltage regulator 3.3v ON", "SLEEP");

    setLogLevel(LOG_INFO);
#if DEBUG_MODE
    print_wakeup_reason();
#endif

    logInfo("Open Ruche Monitoring System Starting...", "SYSTEM");
    // 2. Quick night check (lux only)
    // Bring up I2C just long enough to decide whether we should remain awake.
    Wire.begin(I2C_SDA_PIN, I2C_SCL_PIN);
    delay(20);
    uint16_t lux = read_sen0562();

    char check_msg[96];
    snprintf(check_msg, sizeof(check_msg),
             "Quick  check — lux=%u (threshold=%u)",
             lux,
             LUX_ACTIVITY_THRESHOLD);
    logInfo(check_msg, "SYSTEM");

    if (lux < LUX_ACTIVITY_THRESHOLD) {
        ++dormant_streak;
        snprintf(check_msg, sizeof(check_msg),
                 "Dormant mode (lux=%u) — sleeping %lus [streak %d]",
                 lux,
                 (unsigned long)DEEP_SLEEP_DORMANT_S,
                 dormant_streak);
        logInfo(check_msg, "SYSTEM");
        lora_power_off();
        digitalWrite(VREG_3V3_PIN, LOW);
        digitalWrite(VREG_5V_PIN, LOW);
        logInfo("Voltage regulator 3.3V OFF", "SLEEP");
        logInfo("Voltage regulator 5V OFF", "SLEEP");
#if DEBUG_MODE
        Serial.flush();
#endif
        enter_deep_sleep(DEEP_SLEEP_DORMANT_S);
        return;
    } else {
        dormant_streak = 0;
    }

    // 3. Full wakeup (daytime)
    // We already spent ~200 ms on quick lux check; wait the remaining time
    // for DHT22/DS18B20 stabilization before reading them.
    delay(1800);

#if DEBUG_MODE
    Serial.println("[DEBUG] Starting sensors_init...");
#endif
    sensors_init();
#if DEBUG_MODE
    Serial.println("[DEBUG] sensors_init done");
#endif
    boards_init();

    DHT22Result intr = read_dht22(internal_dht, "Internal DHT22");
    int16_t s1 = read_ds18b20_sonde(sonde1, "DS18B20 Sonde 1");
    int16_t s2 = read_ds18b20_sonde(sonde2, "DS18B20 Sonde 2");

    logInfo("Daylight confirmed — starting uplink cycle", "SYSTEM");

    lora_init();

    // Wait for OTAA join — the LoRa-E5 responds quickly if session is still active.
    logInfo("Waiting for LoRa network join...", "SYSTEM");
    const unsigned long JOIN_TIMEOUT_MS = 15000;
    unsigned long deadline = millis() + JOIN_TIMEOUT_MS;
    while (!lora_is_joined() && millis() < deadline) {
        lora_tick();
        delay(50);
    }

    if (!lora_is_joined()) {
        logError(ERR_TIMEOUT, "LoRa join");
        shutdown_and_sleep(DEEP_SLEEP_LORA_S);
        return;
    }

    logInfo("Reading sensors...", "SYSTEM");

    const LoRaCalibration& cal = lora_calibration();
    SensorPayload payload = {0};

    // External DHT22
    DHT22Result ext = read_dht22(external_dht, "External DHT22");
    payload.ext_humidity = (int8_t)constrain(ext.humidity + cal.humOffset, 0, 100);
    payload.ext_temperature = (ext.temperature != SENSOR_ERROR_VALUE)
                                  ? ext.temperature + cal.tempOffset
                                  : (int16_t)SENSOR_ERROR_VALUE;

    // Internal DHT22 — apply humidity and temperature offsets
    payload.int_humidity = (int8_t)constrain(intr.humidity + cal.humOffset, 0, 100);
    payload.int_temperature = (intr.temperature != SENSOR_ERROR_VALUE)
                                  ? intr.temperature + cal.tempOffset
                                  : (int16_t)SENSOR_ERROR_VALUE;

    // DS18B20 sondes — apply temperature offset
    payload.sonde1_temperature = (s1 != SENSOR_ERROR_VALUE)
                                     ? s1 + cal.tempOffset
                                     : (int16_t)SENSOR_ERROR_VALUE;

    payload.sonde2_temperature = (s2 != SENSOR_ERROR_VALUE)
                                     ? s2 + cal.tempOffset
                                     : (int16_t)SENSOR_ERROR_VALUE;

    // Luminosity
    payload.lux = lux;

    // Weight: net weight after tare (g*100)
    payload.weight = read_hx711();

    digitalWrite(VREG_3V3_PIN, LOW);
    logInfo("Voltage regulator 3.3V OFF", "SLEEP");

    pinMode(VREG_5V_PIN, OUTPUT);
    digitalWrite(VREG_5V_PIN, HIGH);
    logInfo("Voltage regulator 5V ON", "SLEEP");

    deadline = millis() + AI_READ_TIME;
    while (millis() < deadline) {
        payload.audio = read_audio();
        payload.camera = read_camera();
    }

    digitalWrite(VREG_5V_PIN, LOW);
    logInfo("Voltage regulator 5V OFF", "SLEEP");

    // Battery voltage via ADC (GPIO35)
    payload.battery_v = read_battery_v();

    lora_send(payload);

    // Listen long enough to cover RX1/RX2 windows even with scheduling jitter.
    const unsigned long DOWNLINK_LISTEN_MS = 10000;
    logInfo("Listening for downlink window...", "SYSTEM");
    deadline = millis() + DOWNLINK_LISTEN_MS;
    while (millis() < deadline) {
        lora_tick();
        delay(50);
    }
    logInfo("Downlink window closed", "SYSTEM");
    shutdown_and_sleep(lora_sleep_duration_s());
}

void loop() {

}

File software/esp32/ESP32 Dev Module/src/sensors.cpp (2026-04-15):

#include <Arduino.h>
#include "sensors.h"

HX711 hx711;

DHT external_dht(EXTERNAL_DTH22_DATA_PIN, DHT22);
DHT internal_dht(INTERNAL_DTH22_DATA_PIN, DHT22);

OneWire oneWire(ONE_WIRE_BUS);
DallasTemperature sondes(&oneWire);
DeviceAddress sonde1 = {0x28, 0x4C, 0xB5, 0x68, 0x10, 0x00, 0x00, 0x4D}; //fil orange
DeviceAddress sonde2 = {0x28, 0x33, 0xBA, 0x69, 0x10, 0x00, 0x00, 0x11};

void sensors_init(void) {
    // Initialize I2C bus for all I2C sensors (SEN0562, etc.).
#if DEBUG_MODE
    Serial.println("[DEBUG] Wire.begin...");
#endif
    Wire.begin(I2C_SDA_PIN, I2C_SCL_PIN);

    // I2C bus scan
#if DEBUG_MODE
    Serial.println("[DEBUG] I2C scan:");
#endif
    int found = 0;
    for (uint8_t addr = 1; addr < 127; addr++) {
        Wire.beginTransmission(addr);
        if (Wire.endTransmission() == 0) {
#if DEBUG_MODE
            Serial.printf("[DEBUG]   device at 0x%02X\n", addr);
#endif
            found++;
        }
    }
#if DEBUG_MODE
    if (found == 0) Serial.println("[DEBUG]   no I2C devices found");
#endif

#if DEBUG_MODE
    Serial.println("[DEBUG] hx711_init...");
#endif
    hx711_init();
#if DEBUG_MODE
    Serial.println("[DEBUG] DHT begin...");
#endif
	external_dht.begin();
	internal_dht.begin();
    logInfo("DHT22 sensors initialized", "SETUP");
#if DEBUG_MODE
    Serial.println("[DEBUG] sondes_init...");
#endif
    sondes_init();
}

void hx711_init(void) {
    hx711.begin(HX711_DOUT_PIN, HX711_SCK_PIN);
	vTaskDelay(200);
	hx711.set_scale(HX711_SCALE);
	hx711.set_offset(HX711_OFFSET);
	vTaskDelay(200);
    logInfo("HX711 initialized: scale=30148, offset=134750", "SETUP");
}

void sondes_init(void) {
    sondes.begin();
    int deviceCount = sondes.getDeviceCount();
#if DEBUG_MODE
    Serial.printf("[DEBUG] DS18B20 devices found on bus: %d\n", deviceCount);
#endif

    if (deviceCount > 0) {
        sondes.getAddress(sonde1, 0);
#if DEBUG_MODE
        Serial.printf("[DEBUG] Sonde 1 addr: %02X:%02X:%02X:%02X:%02X:%02X:%02X:%02X\n",
            sonde1[0],sonde1[1],sonde1[2],sonde1[3],sonde1[4],sonde1[5],sonde1[6],sonde1[7]);
#endif
    } else {
        logError(ERR_DEVICE_NOT_FOUND, "DS18B20 Sonde 1");
    }

    if (deviceCount > 1) {
        sondes.getAddress(sonde2, 1);
#if DEBUG_MODE
        Serial.printf("[DEBUG] Sonde 2 addr: %02X:%02X:%02X:%02X:%02X:%02X:%02X:%02X\n",
            sonde2[0],sonde2[1],sonde2[2],sonde2[3],sonde2[4],sonde2[5],sonde2[6],sonde2[7]);
#endif
    } else if (deviceCount == 1) {
        logError(ERR_DEVICE_NOT_FOUND, "DS18B20 Sonde 2");
    }

    if (deviceCount > 0)
        logInfo("DS18B20 sensors initialized", "SETUP");
}

uint16_t read_hx711() {
	hx711.power_up();
	float units = hx711.get_units(10);
	hx711.power_down();
	return (uint16_t)(units*100);
}

DHT22Result read_dht22(DHT& dht, const char* sensorName){
	DHT22Result result;
	float humidity = dht.readHumidity();
	float temperature = dht.readTemperature();
	
	if (isnan(humidity) || isnan(temperature)) {
		logError(ERR_SENSOR_READ_FAILED, sensorName);
		result.humidity = 0;
		result.temperature = SENSOR_ERROR_VALUE;
		return result;
	}
	
	result.humidity = (int8_t)humidity;
	result.temperature = (int16_t)(temperature * 10);
	return result;
}

int16_t read_ds18b20_sonde(DeviceAddress sensorAddr, const char* sensorName) {
    sondes.requestTemperatures();
    if (sondes.isConnected(sensorAddr)) {
        float temp = sondes.getTempC(sensorAddr);
        if (temp == DEVICE_DISCONNECTED_C) {
            logError(ERR_SENSOR_READ_FAILED, sensorName);
            return SENSOR_ERROR_VALUE;
        }
        return (int16_t)(temp * 10);
    } else {
        logError(ERR_DEVICE_NOT_FOUND, sensorName);
        return SENSOR_ERROR_VALUE;
    }
}

uint8_t read_battery_v() {
    pinMode(BATTERY_ADC_PIN, INPUT);
    // Average 10 samples to reduce ADC noise
    int sum = 0;
    for (int n = 0; n < 10; n++) sum += analogRead(BATTERY_ADC_PIN);
    float raw    = sum / 10.0f;
    float batt_v = 1.435f * (raw / 4095.0f) * 3.3f;
    // 3.3 V = 0%, 4.2 V = 100%
    float pct = (batt_v - 3.3f) / (4.2f - 3.3f) * 100.0f;
    if(pct > 100.0f) pct = 100.0f;
    if(pct < 0.0f) pct = 0.0f;
    return (uint8_t)pct;
}

uint16_t read_sen0562() {
    // Re-send measurement command after deep sleep wakeup
    Wire.beginTransmission(SEN0562_ADDR);
    Wire.write(0x10); // Continuously H-Resolution Mode
    if (Wire.endTransmission() != 0) {
        logError(ERR_I2C_COMMUNICATION_FAILED, "SEN0562");
        return SENSOR_LUX_ERROR_VALUE;
    }

    delay(180); // BH1750 precisa de até 180ms para medir

    uint8_t buf[2] = {0};
    Wire.requestFrom(SEN0562_ADDR, (size_t)2);
    if (Wire.available() < 2) {
        logError(ERR_INVALID_DATA, "SEN0562");
        return SENSOR_LUX_ERROR_VALUE;
    }
    buf[0] = Wire.read();
    buf[1] = Wire.read();
    uint16_t data = (buf[0] << 8) | buf[1];
    return (uint16_t)(((float)data) / 1.2f);
}

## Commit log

2026-02-17 hw(schematic): initialize KiCad project and create main schematic file
    [open-ruche-monitoring.kicad_pcb, open-ruche-monitoring.kicad_sch]
2026-02-23 feat(hx711): finish HX711 load cell calibration and configuration
2026-02-23 hw(schematic): add sensors to schematic
    [open-ruche-monitoring.kicad_sch]
2026-02-24 refactor: move global sensor definitions to sensors.h and sensors.c files
2026-02-24 feat(sondes): add DS18B20 temperature probes
2026-02-24 feat(light sensor): payload structure + light sensor configured
2026-02-24 feat: add logger system and improve error handling
    [logger.cpp, main.cpp, sensors.cpp]
2026-02-24 feat: read accelerometer MMA 8 451 to the project
2026-02-24 hw(schematic): add acc and 3.3V conversor schematic
    [open-ruche-monitoring.kicad_sch]
2026-02-24 hw(schematic): changes to 3.3V conversor footprint
2026-03-02 fix(sensors): set fixed offset for HX711 tare value
    [main.cpp]
2026-03-02 hw(schematic): schematic done
    [open-ruche-monitoring.kicad_pcb, open-ruche-monitoring.kicad_sch]
2026-03-09 hw(3D) Add 3D models for lora, hx711 and lipo charger
    [open-ruche-monitoring.kicad_pcb, open-ruche-monitoring.kicad_sch]
2026-03-09 hw(pcb) save pcb to try another layout
    [open-ruche-monitoring.kicad_pcb, open-ruche-monitoring.kicad_sch]
2026-03-09 refactor: modularize project structure and improve sensor initialization logging
2026-03-10 hw(pcb) pcb done
    [open-ruche-monitoring.kicad_pcb, open-ruche-monitoring.kicad_sch]
2026-03-10 hw(pcb) main pcb changes
    [open-ruche-monitoring.kicad_pcb, open-ruche-monitoring.kicad_sch]
2026-03-10 hw(pcb) pcb xiao
    [Xiao.kicad_pcb, Xiao.kicad_sch]
2026-03-10 hw(pcb) gerber files
    [Arduino.kicad_pcb, Arduino.kicad_sch, open-ruche-monitoring.kicad_pcb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]
2026-03-24 hw(pcb) final commit pcb
2026-04-02 refactor boards function names + LoRa config to receive downlink
2026-04-10 bug fix: LoRa wakeup
    [config.h, main.cpp]
2026-04-10 bug fix: dormant mode
    [config.h, main.cpp, sleep.cpp]
2026-04-13 fix: lux sleep consummation
    [boards.cpp, config.h, logger.cpp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]
